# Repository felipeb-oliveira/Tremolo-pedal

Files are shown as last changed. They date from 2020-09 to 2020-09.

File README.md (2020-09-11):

# Tremolo pedal

## About
A Tremolo effect pedal, which modulates the guitar signal's amplitude by a generated triangular wave with adjustable frequency. The modulation frequency range is from about 0.5Hz to 10Hz. The circuit has the following stages:

1. Input: guitar signal reception by a P10 (6.35mm) Jack;
2. Oscillator: using a NE555, a square symmetrycal wave is generated, and converted to a triangular wave (with the frequency adjustable by a potentiometer). The wave then passes through a Op Amp buffer;
3. Amplification: The guitar signal is amplified by a ratio of about 2.5 with no distortion/clipping. This is needed because there is power loss at the modulation stage;
4. Modulation: After the amplification, the guitar signal goes through a variable resistor (representing the 'Depth' of the effect) in series with a LDR (Light Dependent Resistor), illuminated by a Led supplied by the oscillator (see the schematic, might get confusing). When the generated wave (from -2V to +2V) is > 0, the LED lights up and the LDR reduces its resistance greatly (from about 2M to about 50k on the best scenario), and the output is the tension divided by these 2 resistors. Since the LDR resistance never reaches zero, there is power loss. Hence, the amplification stage is required. It's basically a voltage divider, with the grounded resistance being the LDR (varying from 2M to 50k), and the 'supply' resistance being the Depth level.
5. Output: modulated signal goes to a P10 Jack.

## Schematic
*These are only the oscillator and modulation circuits, without the inputs, outputs and supply circuits. Please open the Eagle project for the full circuit.*

Oscillator:

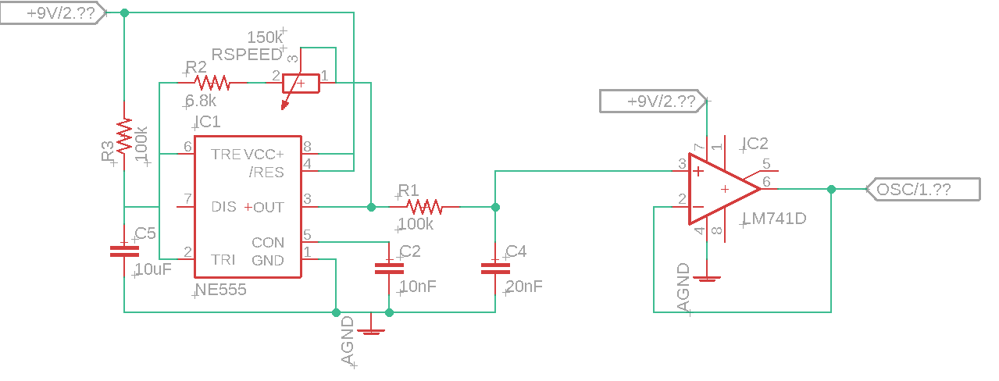
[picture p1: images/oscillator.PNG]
Oscillator schematic


Modulation:

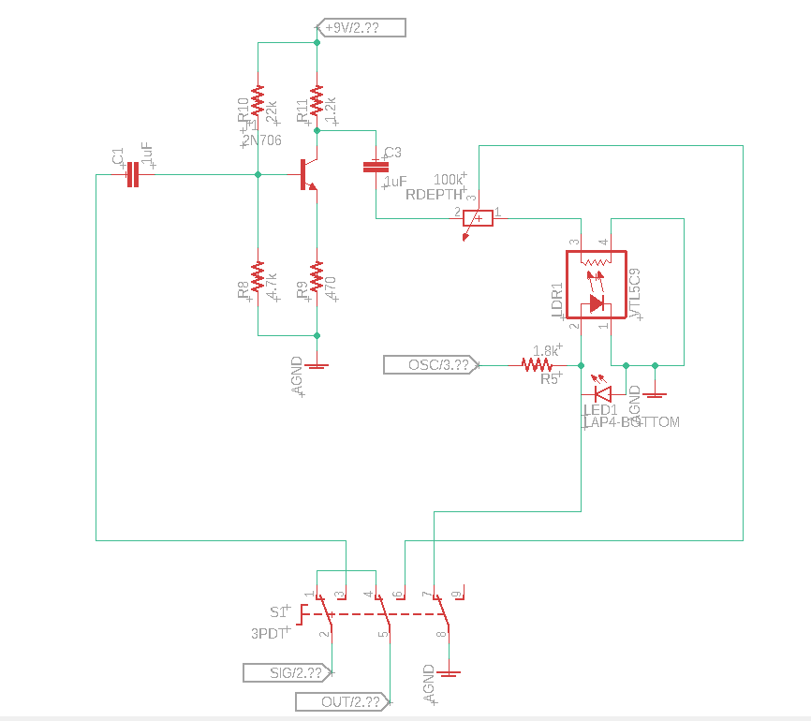
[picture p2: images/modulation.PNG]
Modulation schematic


## Board
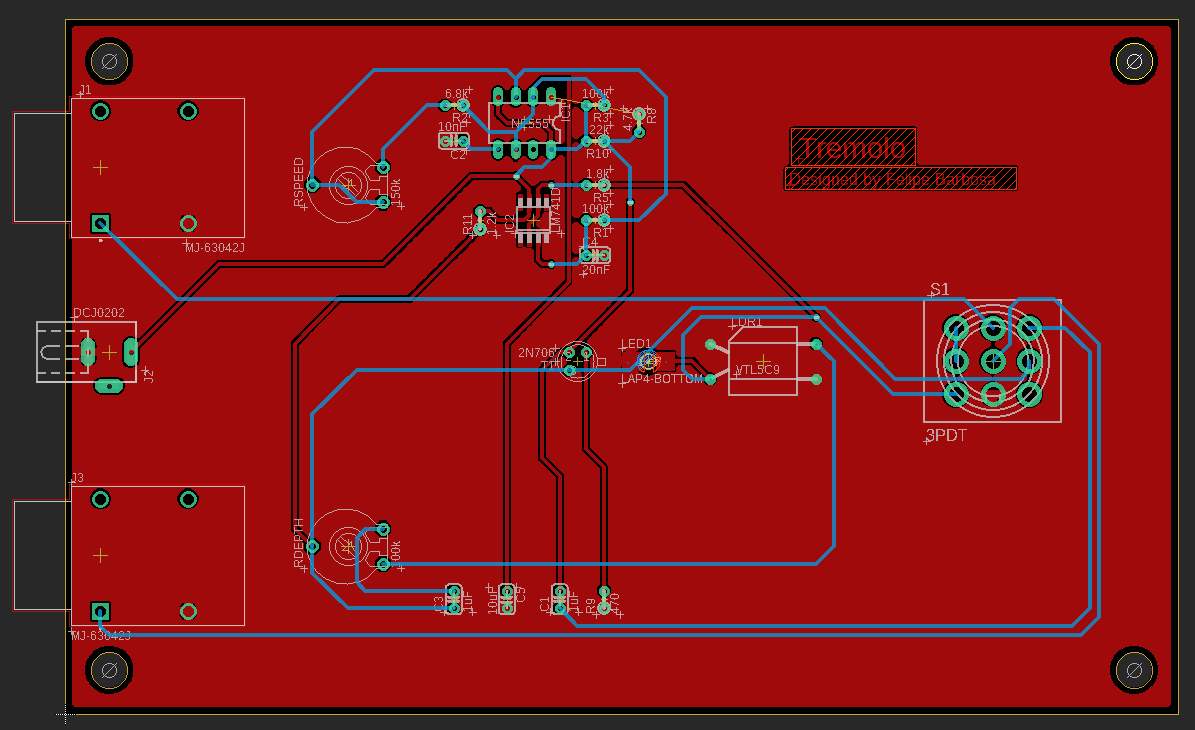
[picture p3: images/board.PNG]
Board


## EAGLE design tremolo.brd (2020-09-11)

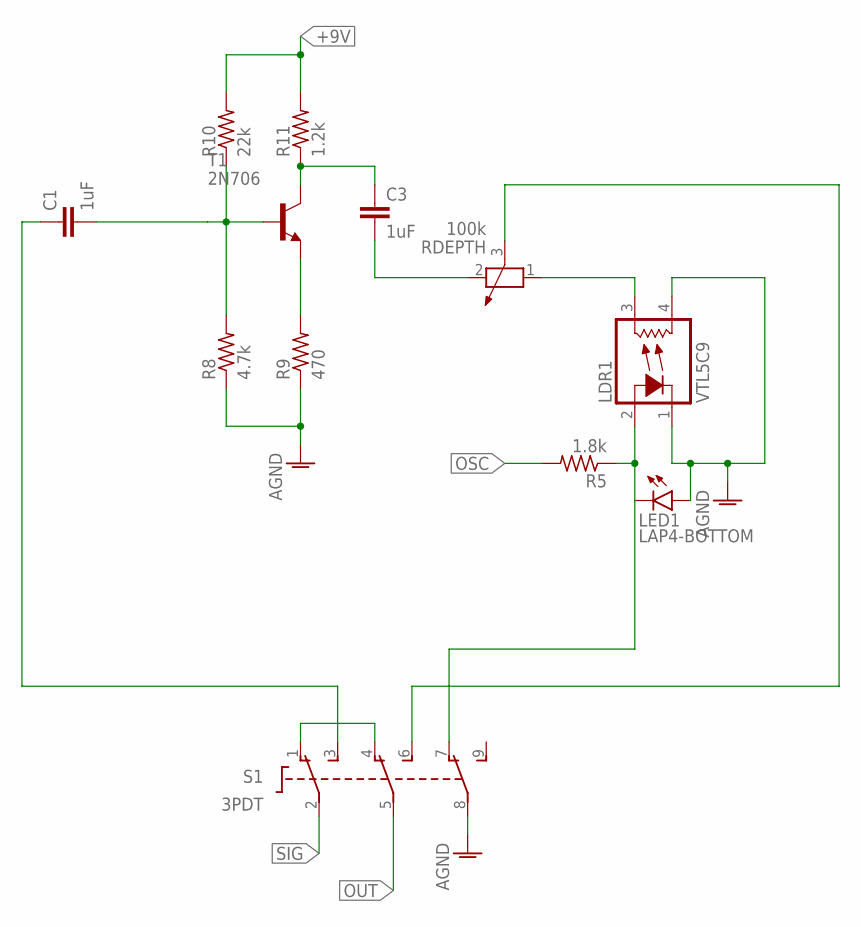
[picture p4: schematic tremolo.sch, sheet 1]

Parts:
C1, C3: 1uF; C025-024X044
LDR1: VTL5C9; VTL5C
LED1: LAP4-BOTTOM; P47F-BOTTOM
R5: 1.8k; 0204V
R8: 4.7k; 0204V
R9: 470; 0204V
R10: 22k; 0204V
R11: 1.2k; 0204V
RDEPTH: 100k; PT-10
S1: 3PDT
T1: 2N706; TO18

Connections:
+9V: R10.2, R11.2; also elsewhere on the board
AGND: LDR1.1 (C), LDR1.4 (L2), LED1.A, R8.1, R9.1, S1.8 (P3); also elsewhere on the board
EFX: C3.1, R11.1, RDEPTH.3, S1.6 (S2), T1.3 (C)
IN: C1.1, S1.3 (S1)
unnamed: R9.2, T1.1 (E)
unnamed: C1.2, R8.2, R10.1, T1.2 (B)
unnamed: LDR1.2 (A), LED1.C, R5.1, S1.7 (O3)
unnamed: LDR1.3 (L1), RDEPTH.1
unnamed: S1.1 (O1), S1.4 (O2)
unnamed: C3.2, RDEPTH.2
OSC: R5.2; also elsewhere on the board
OUT: S1.5 (P2); also elsewhere on the board
SIG: S1.2 (P1); also elsewhere on the board

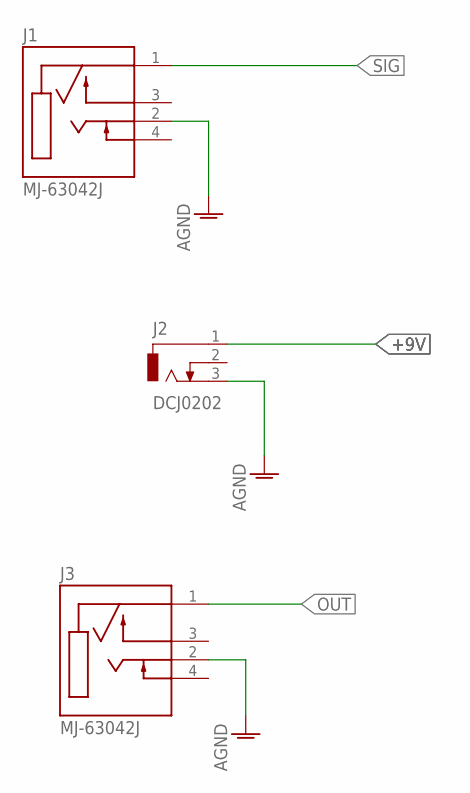
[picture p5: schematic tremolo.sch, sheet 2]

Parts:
J1, J3: MJ-63042J; CUI_MJ-63042J
J2: DCJ0202

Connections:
+9V: J2.1; also elsewhere on the board
AGND: J1.2 (TIP), J2.3, J3.2 (TIP); also elsewhere on the board
OUT: J3.1 (SLEEVE); also elsewhere on the board
SIG: J1.1 (SLEEVE); also elsewhere on the board

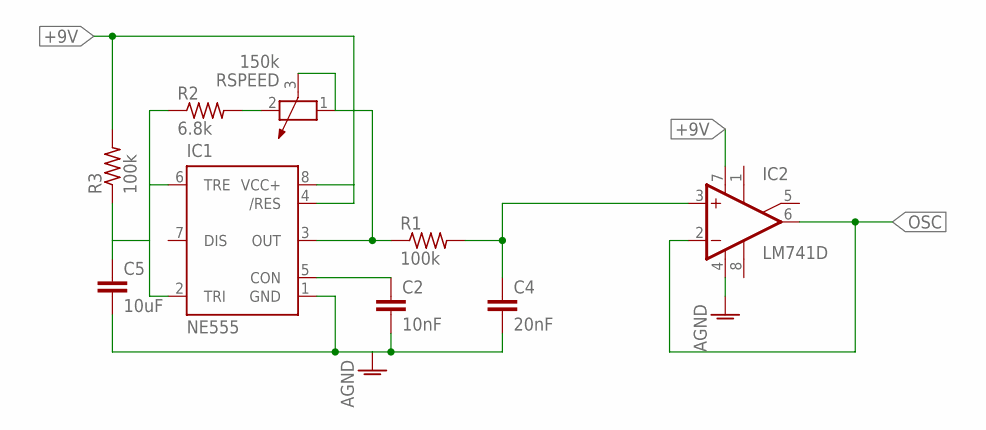
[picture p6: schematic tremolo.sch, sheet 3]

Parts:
C2: 10nF; C025-024X044
C4: 20nF; C025-024X044
C5: 10uF; C025-024X044
IC1: NE555; DIL-08
IC2: LM741D; SO08
R1, R3: 100k; 0204V
R2: 6.8k; 0204V
RSPEED: 150k; PT-10

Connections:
+9V: IC1.4 (/RES), IC1.8 (VCC+), IC2.7 (V+), R3.2; also elsewhere on the board
AGND: C2.2, C4.2, C5.2, IC1.1 (GND), IC2.4 (V-); also elsewhere on the board
unnamed: C2.1, IC1.5 (CON)
unnamed: IC1.3 (OUT), R1.1, RSPEED.1, RSPEED.3
unnamed: C5.1, IC1.2 (TRI), IC1.6 (TRE), R2.1, R3.1
unnamed: R2.2, RSPEED.2
OSC: IC2.2 (-IN), IC2.6 (OUT); also elsewhere on the board
WAV: C4.1, IC2.3 (+IN), R1.2

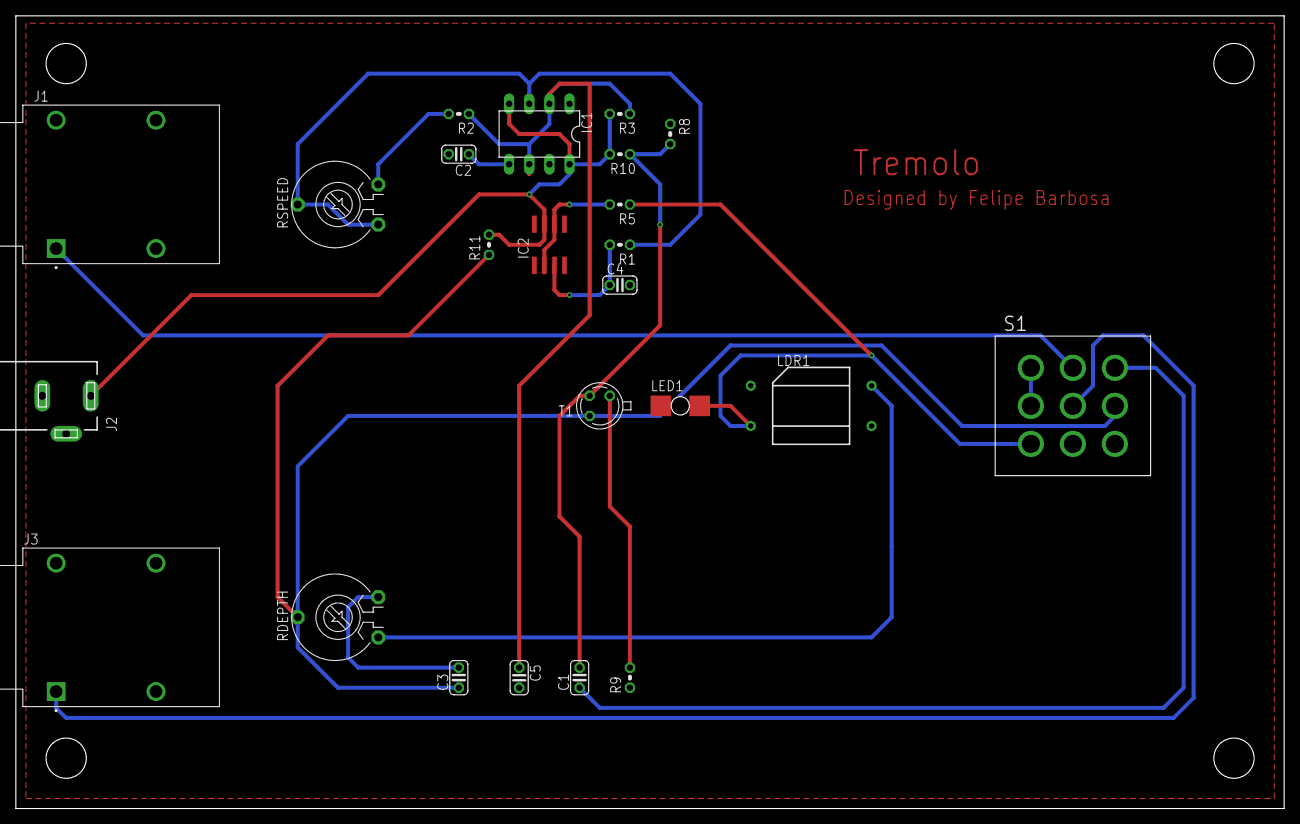
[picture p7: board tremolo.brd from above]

Board: 2 copper layers, 160.0 x 100.0 mm, 24 parts (0 on the bottom side), 18 nets.
